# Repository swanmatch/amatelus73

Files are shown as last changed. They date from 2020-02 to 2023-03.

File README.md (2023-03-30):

# Amatelus73ビルドガイド

## 概要

m.teiさんの[セミエルゴレイアウト](https://github.com/mtei/SemiErgo_Layout)を参考に作成したシンメトリカルスタッガードキーボード。  
RGBMATRIXに標準対応しているのも特徴。

### 材料リスト

| 品目 | 数量 | 備考 |
| :--- | ---: | :--- |
| PCB |  1枚 |  |
| トッププレート |  1枚 |  |
| ボトムプレート |  1枚 |  |
| アクリル保護プレート |  2枚 |  |
| ProMicro |  1個 |  |
| ダイオード | 73個 | スピーカーを使う場合74個。<br>スルーホールは使えないので注意。 |
| LED(YS-SK6812mini) | 74個 |  |
| Kailhソケット | 73個 |  |
| M2L4ネジ | 18本 |  |
| M2L7六角スペーサ |  5本 |  |
| M2L8丸スペーサ |  4本 |  |
| タクトスイッチ |  1個 |  |
| ゴム足 |  4個 |  |
| 2Uスタビライザー |  4個 |  |
| MX互換スイッチ | 73個 |  |
| キーキャップ | 73個 |  |
| USBケーブル |  1本 |  |

### オプション機能

| 品目 | 数量 | 備考 |
| :--- | ---: | :--- |
| コンスルー |  2本 |  |
| 圧電サウンダ |  1個 | スピーカーオプション<br>型番: PKMCS1212E4000-R1 |
| 1kΩ抵抗 |  1個 | スピーカーオプション |
| OLED |  1個 | ピン、ソケットも。 |

## 組み立て手順

### LED

LEDをはんだ付けします。  
小さくドットが入っているのが欠けている足に対応しています。

行ごと向きが違うので注意してください。

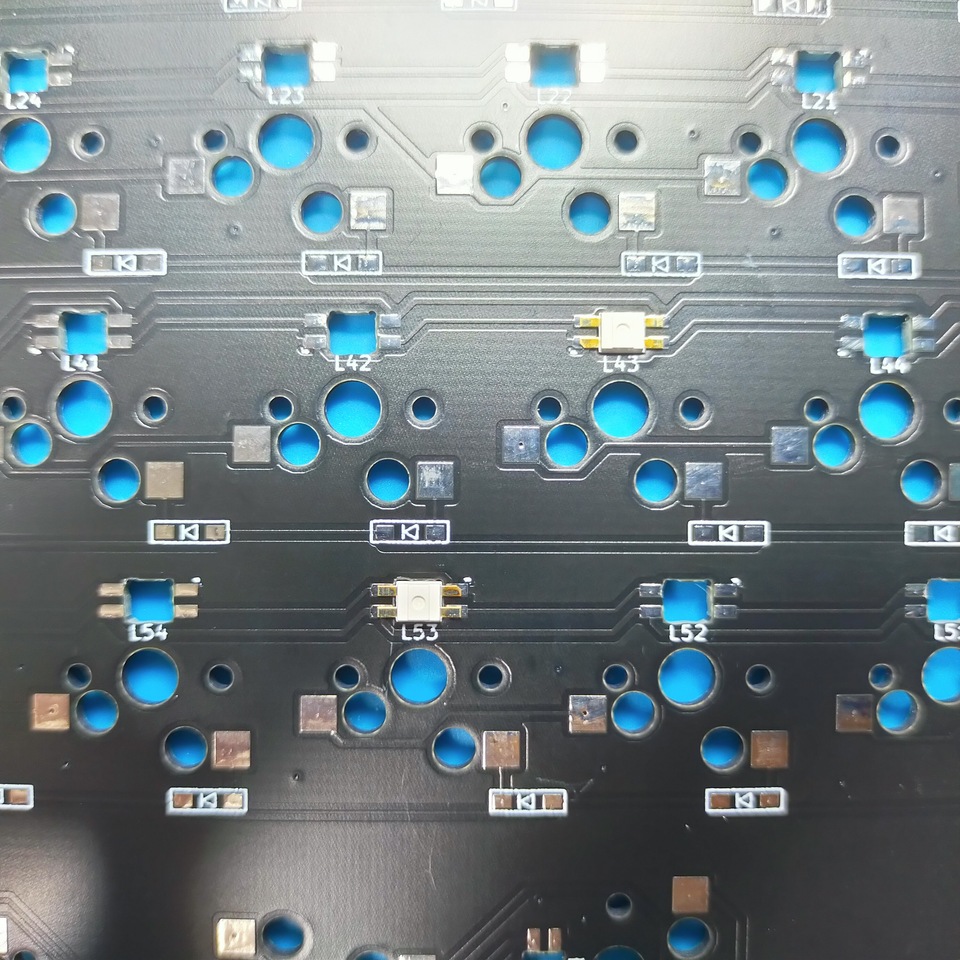
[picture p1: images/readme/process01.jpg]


### ダイオード

ダイオードをはんだ付けします。  
向きに気をつけてください。  
うっすら線が書いてあるほうが左です。

先に予備ハンダとしてどちらかのパッドにハンダを盛って、
予備ハンダを溶かすようにしてダイオードの片足をはんだ付けします。  
この状態で横から見てダイオードが浮いていないことを確認してください。  
浮いてしまっている場合はダイオードをピンセットで押さえつけながら、
はんだづけした部分を再度熱すればきれいになります。

浮いていないことを確認し、反対側をはんだ付けします。

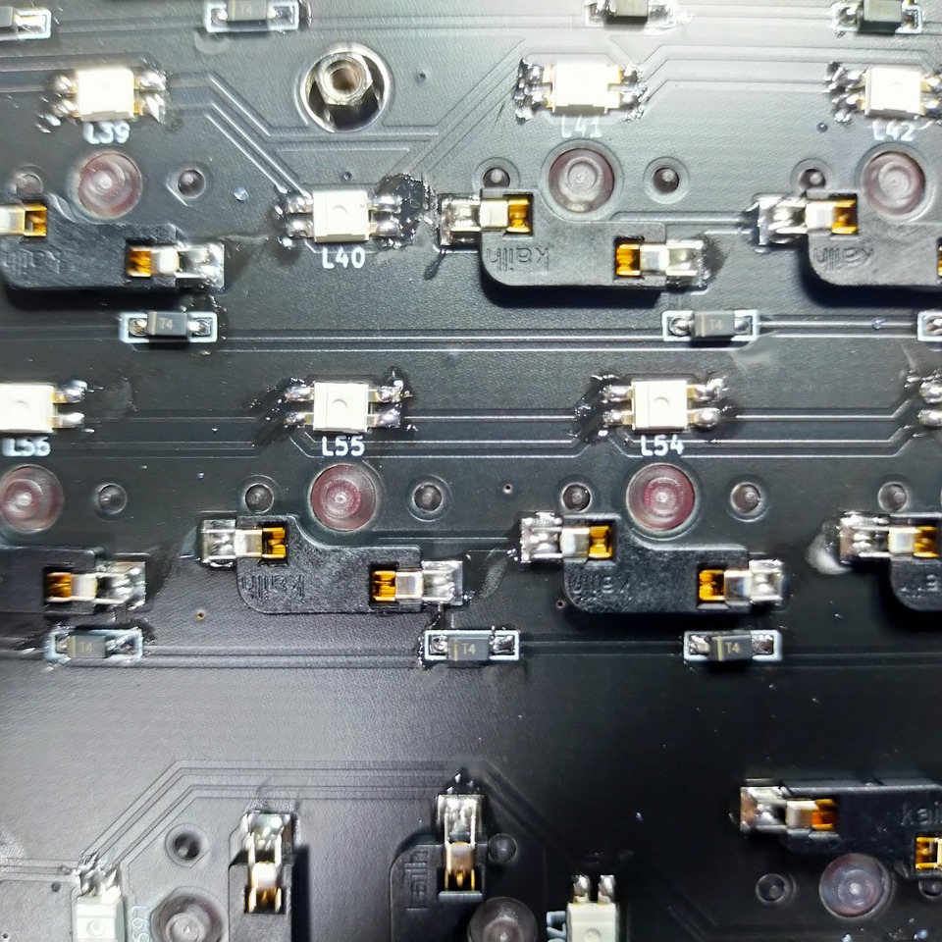
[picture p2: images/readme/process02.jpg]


### ソケット

ソケットをはんだ付けします。

### リセットスイッチ

反対側(表、スイッチ側)にひっくり返して、
タクトスイッチを差し込み、
再度裏面に戻してはんだ付けします。

### 圧電サウンダ(オプション)

1kΩ抵抗、ダイオード、圧電サウンダをはんだ付けします。

### ProMicro

ここだけは間違えるとリカバリが面倒なので、**細心の注意**をして作業にあたってください  
コンスルーを使う場合は[Helixのビルドガイド](https://github.com/MakotoKurauchi/helix/blob/master/Doc/buildguide_jp.md#pro-micro)などを参考にしてください。  
また、ProMicroはあらかじめいわゆる「モゲ対策」をしておくといいです。

まず4角のピンをはんだ付けし、
ピンヘッダとプロマイクロが浮いていないことを確認して、
他のピンをはんだ付けします。  
浮いてしまっていた場合、やけどに気を付けて、指で少し抑えながら、
浮いているピンにハンダをあてます。
裏面に戻し、表面と同様に4角からはんだ付けしていきます。

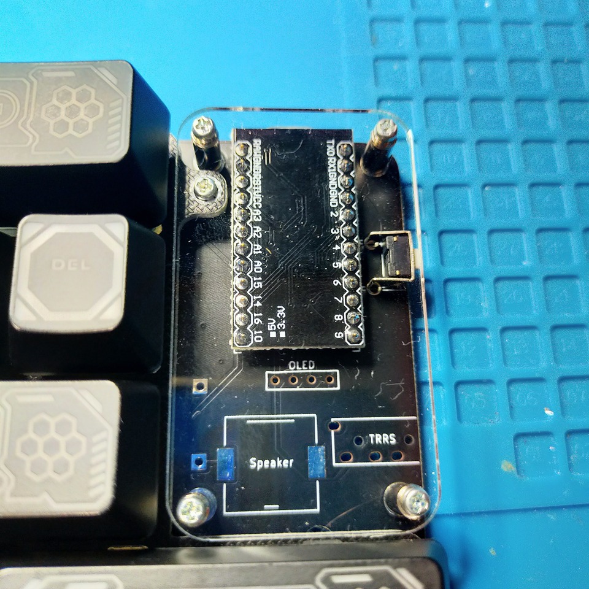
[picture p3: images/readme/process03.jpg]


この段階で一度後述のLEDテスト用のファームウェアの書き込みをして導通テストしておくといいです。  
問題なければ全LEDが点灯するはずです。  
(RGB_MATRIXはキー押下に応じてLEDが光るモードがデフォルトになっているようなのでLED_testで確認するのが吉です。)

```sh
git clone https://github.com/swanmatch/qmk_firmware.git --recursive
cd qmk_firmware
make amatelus73:led_test:avrdude
```

### OLED(オプション)

OLEDにピンをはんだ付けし、基板側にソケットをはんだ付けします。
いずれも斜めになりやすいので注意してください。

### スタビライザ

スタビライザを組み立てて、回路基板にはめ込みます。

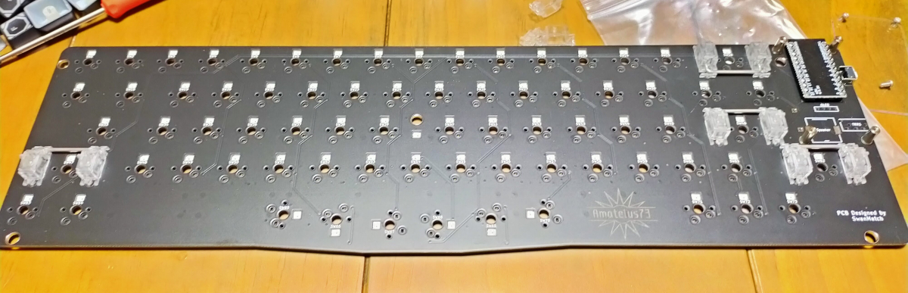
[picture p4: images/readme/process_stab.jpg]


### スイッチ、トッププレート

トッププレートにスイッチをはめて、PCBに刺します。  
これも最初に4角からはめるといいです。

### プロマイクロ保護プレート

PCB裏側から丸スペーサーをネジ止めして、
表側に保護プレートを挟み込む形でPCネジで止めます。

### ボトムプレート

ボトムプレートに六角スペーサーをネジ止めして、
本体にはめ込み、ネジ止めします。

ボトムプレートにゴム足を貼り付けてください。

### ファームウェア

ファームウェアの書き込みは以下のコマンドを叩きます。  
QMKの環境構築についてはお使いのOSによって異なりなりますので、
公式ドキュメントを読んでください。
```sh
# LEDテストの書き込みを実施した場合は↓は不要
git clone https://github.com/swanmatch/qmk_firmware.git --recursive
cd qmk_firmware
make amatelus73:default:avrdude
# OLED ver
# amatelus73/oled:default:avrdude
# Audio ver
# amatelus73/audio:default:avrdude
```

### キーキャップ

キーキャップの取り付けは下記を推奨しています。  
図はm.teiさんに作成いただきました。

Special Thanks!!

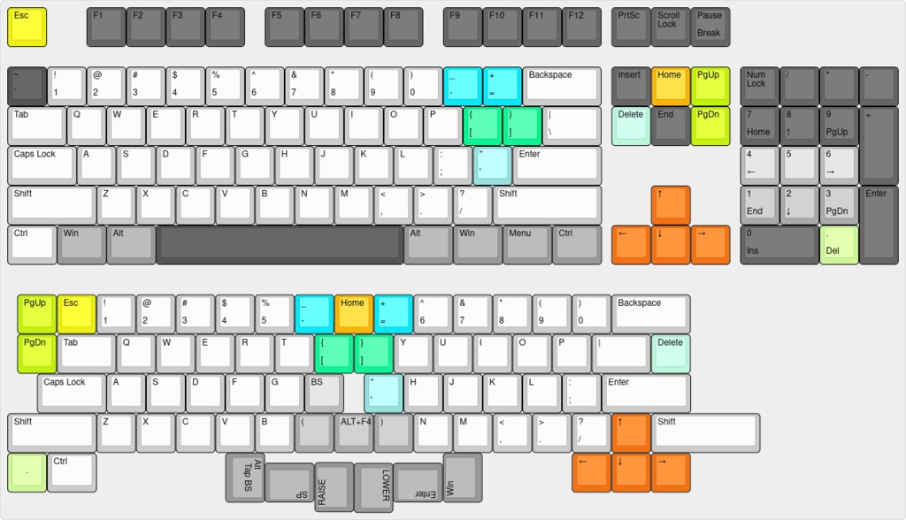
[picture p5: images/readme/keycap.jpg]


## 完成図

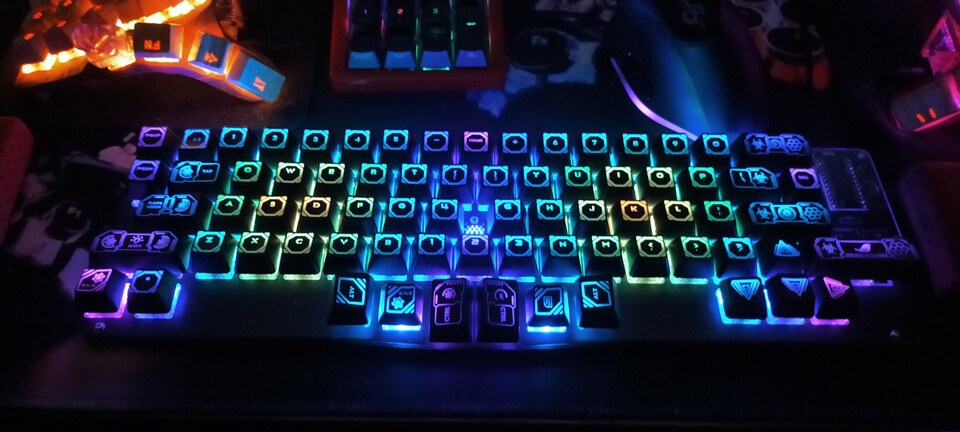
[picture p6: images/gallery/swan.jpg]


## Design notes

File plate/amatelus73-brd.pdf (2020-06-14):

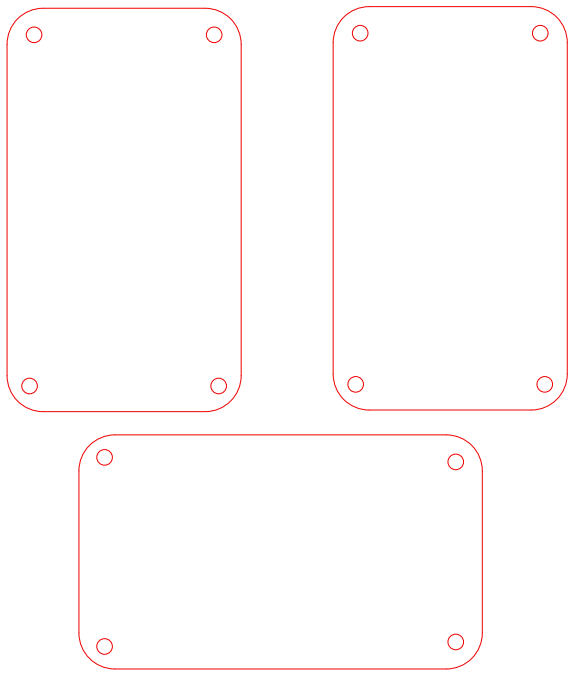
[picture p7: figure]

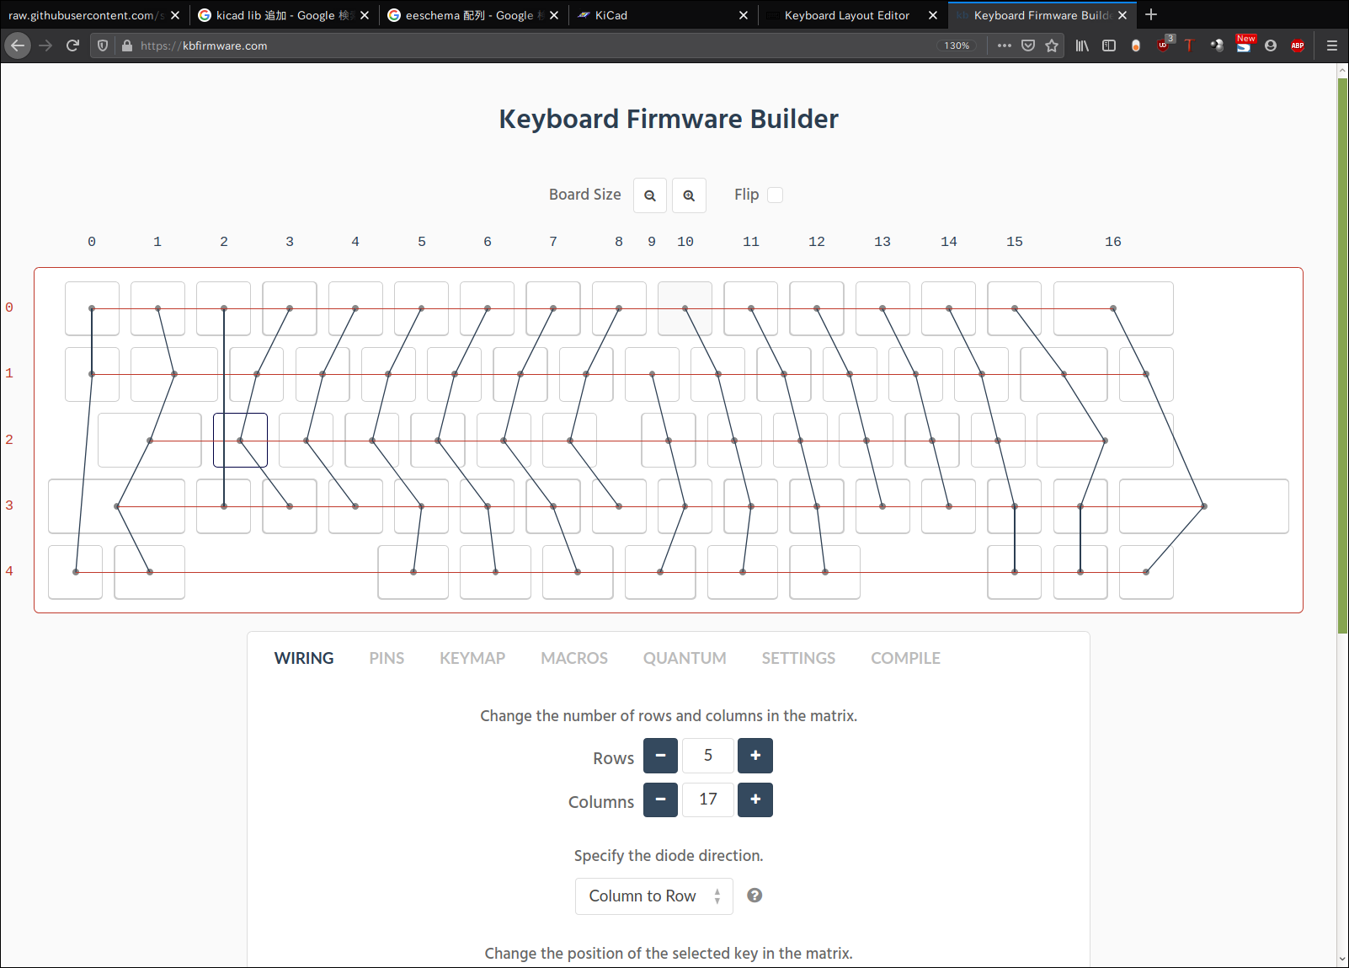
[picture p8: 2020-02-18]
haisen.png

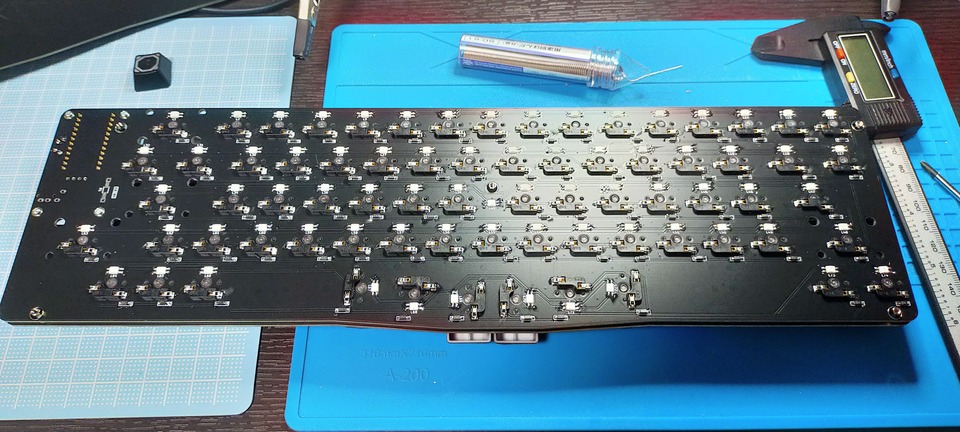
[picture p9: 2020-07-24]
images/readme/all.jpg

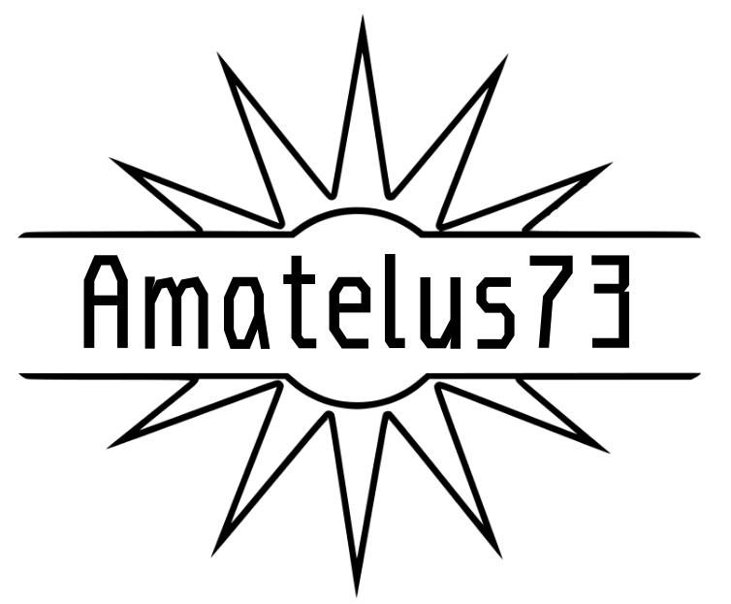
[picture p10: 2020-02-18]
bottom/amatelus73.png

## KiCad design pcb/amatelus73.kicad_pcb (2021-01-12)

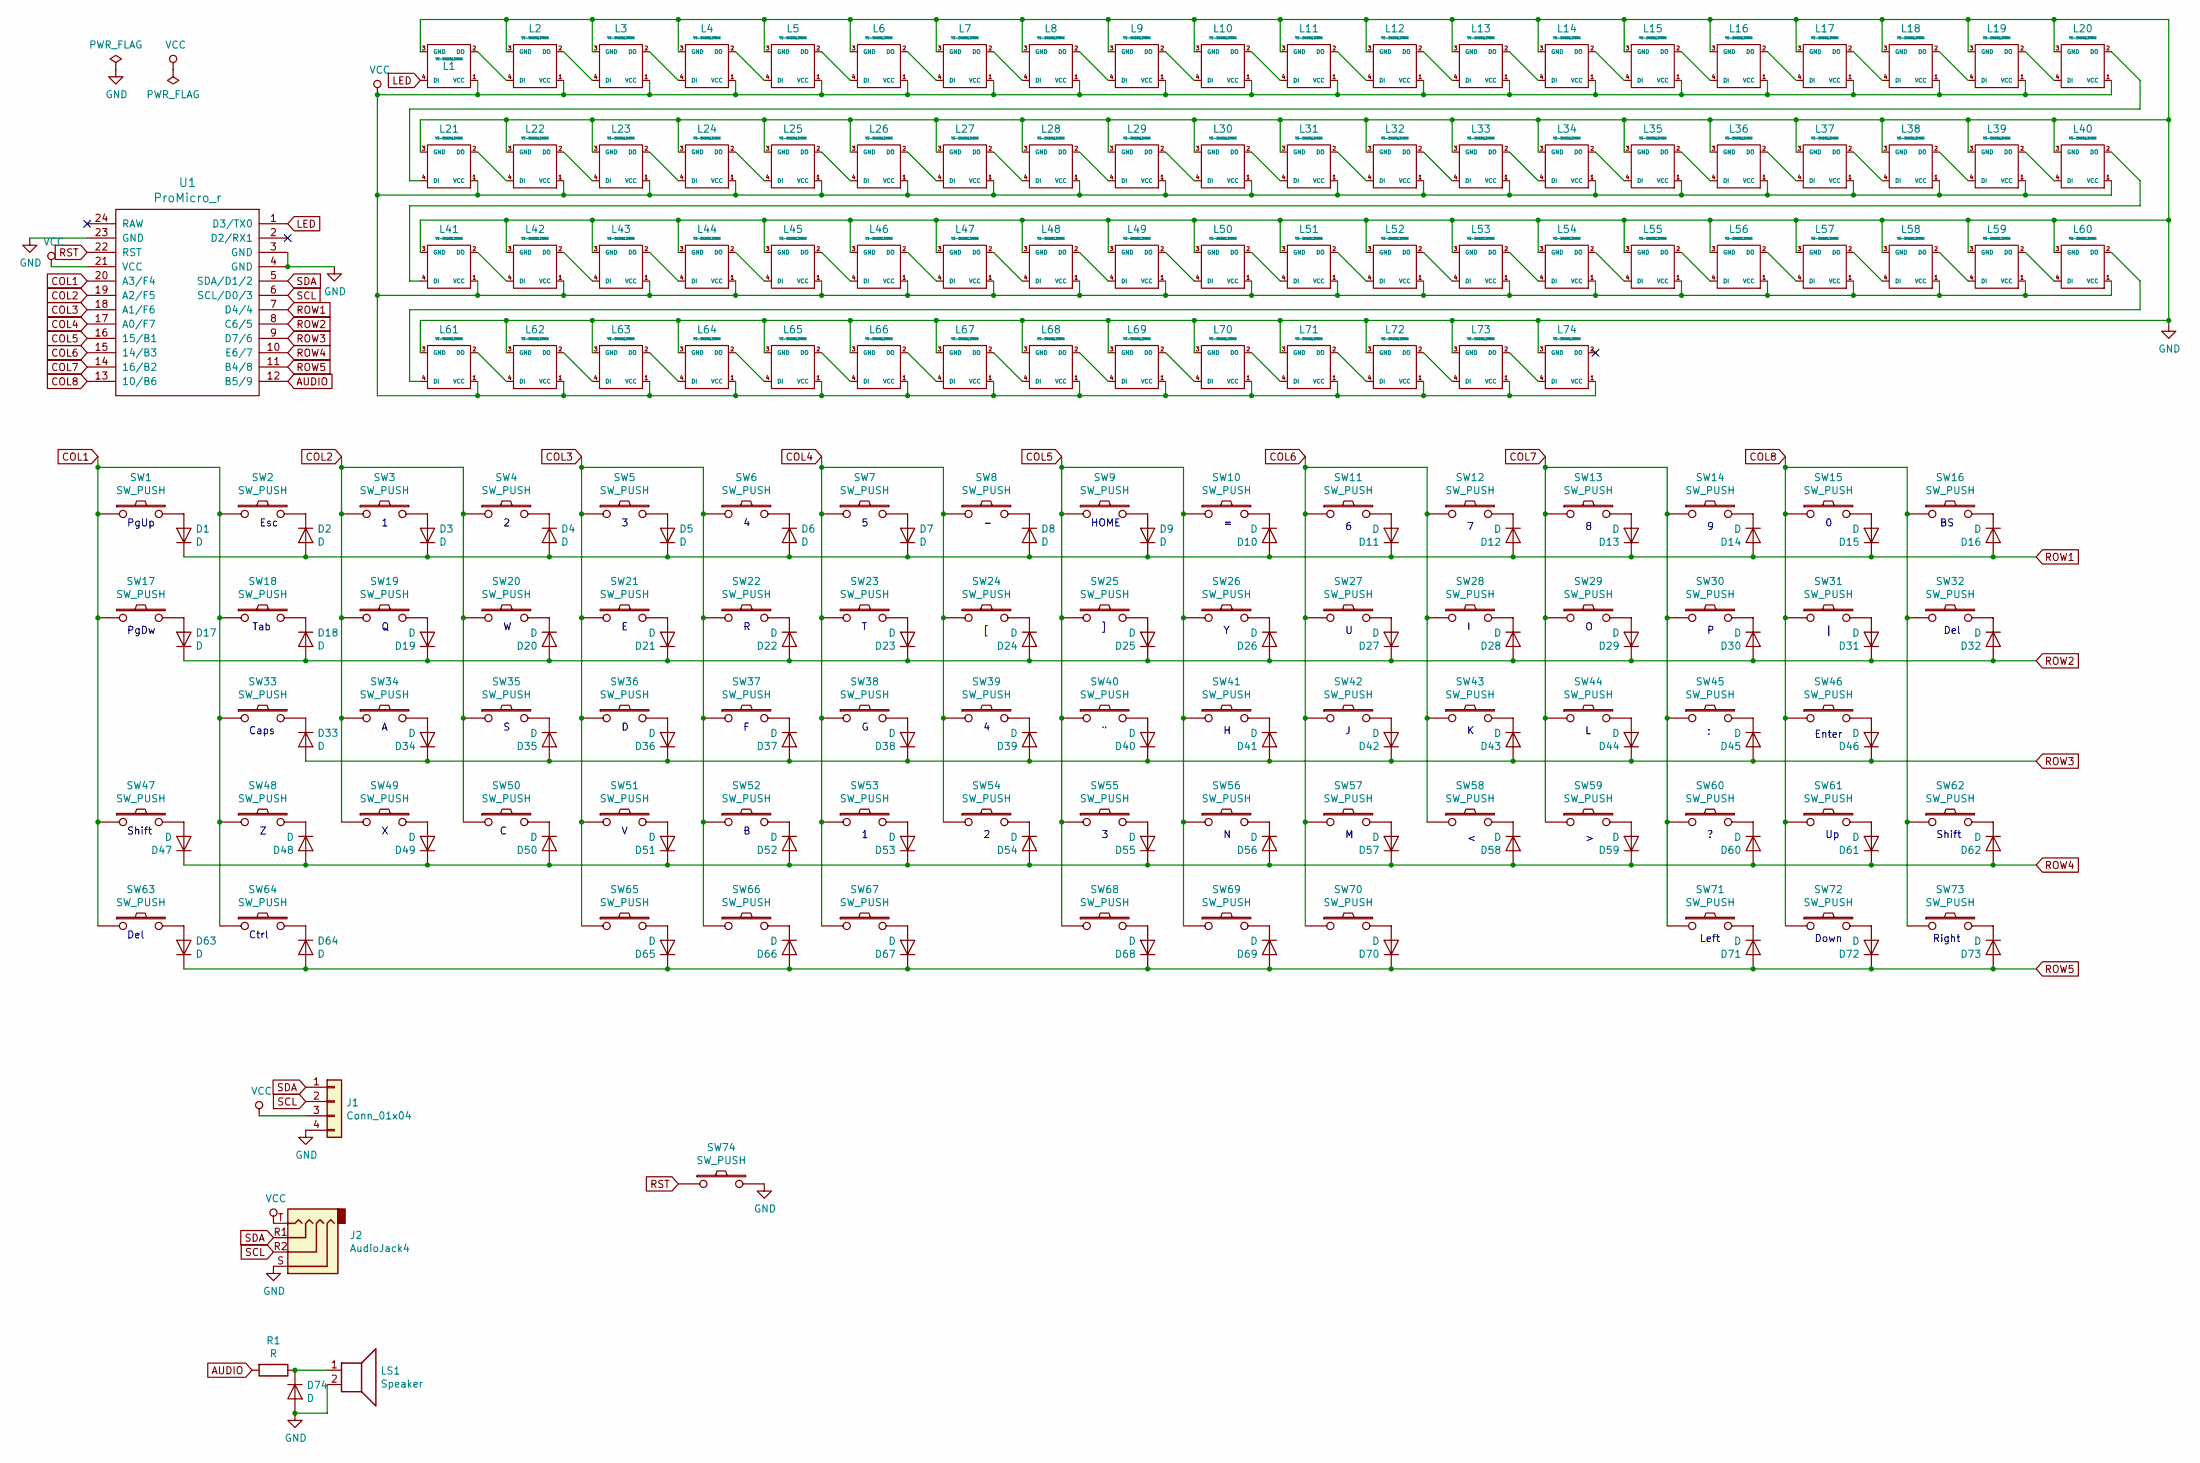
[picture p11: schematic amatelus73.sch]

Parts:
D1, D2, D3, D4, D5, D6, D7, D8, D9, D10, D11, D12, D13, D14, D15, D16, D17, D18, D19, D20, D21, D22, D23, D24, D25, D26, D27, D28, D29, D30, D31, D32, D33, D34, D35, D36, D37, D38, D39, D40, D41, D42, D43, D44, D45, D46, D47, D48, D49, D50, D51, D52, D53, D54, D55, D56, D57, D58, D59, D60, D61, D62, D63, D64, D65, D66, D67, D68, D69, D70, D71, D72, D73, D74: D; D3_SMD
J1: Conn_01x04; OLED_1side
J2: AudioJack4; MJ-4PP-9
L1, L2, L3, L4, L5, L6, L7, L8, L9, L10, L11, L12, L13, L14, L15, L16, L17, L18, L19, L20, L21, L22, L23, L24, L25, L26, L27, L28, L29, L30, L31, L32, L33, L34, L35, L36, L37, L38, L39, L40, L41, L42, L43, L44, L45, L46, L47, L48, L49, L50, L51, L52, L53, L54, L55, L56, L57, L58, L59, L60, L61, L62, L63, L64, L65, L66, L67, L68, L69, L70, L71, L72, L73, L74: YS-SK6812MINI; YS-SK6812MINI-E
LS1: Speaker; PKLCS1212E4001_HandSoldering
R1: R; Resistor_SMD+THTuniversal_1206_RM10_HandSoldering
SW1, SW2, SW3, SW4, SW5, SW6, SW7, SW8, SW9, SW10, SW11, SW12, SW13, SW14, SW15, SW16, SW17, SW19, SW20, SW21, SW22, SW23, SW24, SW25, SW26, SW27, SW28, SW29, SW30, SW32, SW34, SW35, SW36, SW37, SW38, SW39, SW40, SW41, SW42, SW43, SW44, SW45, SW48, SW49, SW50, SW51, SW52, SW53, SW54, SW55, SW56, SW57, SW58, SW59, SW60, SW61, SW63, SW71, SW72, SW73: SW_PUSH; CherryMX_Hotswap
SW18, SW31: SW_PUSH; CherryMX_Hotswap_1.5u
SW33: SW_PUSH; CherryMX_Hotswap_1.75u
SW46: SW_PUSH; CherryMX_Hotswap_2.25u
SW47, SW64, SW65, SW66, SW67, SW68, SW69, SW70: SW_PUSH; CherryMX_Hotswap_1.25u
SW62: SW_PUSH; CherryMX_Hotswap_2.75u
SW74: SW_PUSH; tact_switch2
U1: ProMicro_r; ProMicro_v3

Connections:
AUDIO: R1.2, U1.12 (B5/9)
COL1: SW1.1, SW2.1, SW17.1, SW18.1, SW33.1, SW47.1, SW48.1, SW63.1, SW64.1, U1.20 (A3/F4)
COL2: SW3.1, SW4.1, SW19.1, SW20.1, SW34.1, SW35.1, SW49.1, SW50.1, U1.19 (A2/F5)
COL3: SW5.1, SW6.1, SW21.1, SW22.1, SW36.1, SW37.1, SW51.1, SW52.1, SW65.1, SW66.1, U1.18 (A1/F6)
COL4: SW7.1, SW8.1, SW23.1, SW24.1, SW38.1, SW39.1, SW53.1, SW54.1, SW67.1, U1.17 (A0/F7)
COL5: SW9.1, SW10.1, SW25.1, SW26.1, SW40.1, SW41.1, SW55.1, SW56.1, SW68.1, SW69.1, U1.16 (15/B1)
COL6: SW11.1, SW12.1, SW27.1, SW28.1, SW42.1, SW43.1, SW57.1, SW58.1, SW70.1, U1.15 (14/B3)
COL7: SW13.1, SW14.1, SW29.1, SW30.1, SW44.1, SW45.1, SW59.1, SW60.1, SW71.1, U1.14 (16/B2)
COL8: SW15.1, SW16.1, SW31.1, SW32.1, SW46.1, SW61.1, SW62.1, SW72.1, SW73.1, U1.13 (10/B6)
GND: D74.2 (A), J1.4, J2.S, L1.3 (GND), L2.3 (GND), L3.3 (GND), L4.3 (GND), L5.3 (GND), L6.3 (GND), L7.3 (GND), L8.3 (GND), L9.3 (GND), L10.3 (GND), L11.3 (GND), L12.3 (GND), L13.3 (GND), L14.3 (GND), L15.3 (GND), L16.3 (GND), L17.3 (GND), L18.3 (GND), L19.3 (GND), L20.3 (GND), L21.3 (GND), L22.3 (GND), L23.3 (GND), L24.3 (GND), L25.3 (GND), L26.3 (GND), L27.3 (GND), L28.3 (GND), L29.3 (GND), L30.3 (GND), L31.3 (GND), L32.3 (GND), L33.3 (GND), L34.3 (GND), L35.3 (GND), L36.3 (GND), L37.3 (GND), L38.3 (GND), L39.3 (GND), L40.3 (GND), L41.3 (GND), L42.3 (GND), L43.3 (GND), L44.3 (GND), L45.3 (GND), L46.3 (GND), L47.3 (GND), L48.3 (GND), L49.3 (GND), L50.3 (GND), L51.3 (GND), L52.3 (GND), L53.3 (GND), L54.3 (GND), L55.3 (GND), L56.3 (GND), L57.3 (GND), L58.3 (GND), L59.3 (GND), L60.3 (GND), L61.3 (GND), L62.3 (GND), L63.3 (GND), L64.3 (GND), L65.3 (GND), L66.3 (GND), L67.3 (GND), L68.3 (GND), L69.3 (GND), L70.3 (GND), L71.3 (GND), L72.3 (GND), L73.3 (GND), L74.3 (GND), LS1.2, SW74.2, U1.3 (GND), U1.4 (GND), U1.23 (GND); also elsewhere on the board
LED: L1.4 (DI), U1.1 (D3/TX0)
unnamed: D1.2 (A), SW1.2
unnamed: D2.1 (K), SW2.2
unnamed: D3.2 (A), SW3.2
unnamed: D4.1 (K), SW4.2
unnamed: D5.2 (A), SW5.2
unnamed: D6.1 (K), SW6.2
unnamed: D7.2 (A), SW7.2
unnamed: D8.1 (K), SW8.2
unnamed: D9.2 (A), SW9.2
unnamed: D10.1 (K), SW10.2
unnamed: D11.2 (A), SW11.2
unnamed: D12.1 (K), SW12.2
unnamed: D13.2 (A), SW13.2
unnamed: D14.1 (K), SW14.2
unnamed: D15.2 (A), SW15.2
unnamed: D16.1 (K), SW16.2
unnamed: D17.2 (A), SW17.2
unnamed: D18.1 (K), SW18.2
unnamed: D19.2 (A), SW19.2
unnamed: D20.1 (K), SW20.2
unnamed: D21.2 (A), SW21.2
unnamed: D22.1 (K), SW22.2
unnamed: D23.2 (A), SW23.2
unnamed: D24.1 (K), SW24.2
unnamed: D25.2 (A), SW25.2
unnamed: D26.1 (K), SW26.2
unnamed: D27.2 (A), SW27.2
unnamed: D28.1 (K), SW28.2
unnamed: D29.2 (A), SW29.2
unnamed: D30.1 (K), SW30.2
unnamed: D31.2 (A), SW31.2
unnamed: D32.1 (K), SW32.2
unnamed: D33.1 (K), SW33.2
unnamed: D34.2 (A), SW34.2
unnamed: D35.1 (K), SW35.2
unnamed: D36.2 (A), SW36.2
unnamed: D37.1 (K), SW37.2
unnamed: D38.2 (A), SW38.2
unnamed: D39.1 (K), SW39.2
unnamed: D40.2 (A), SW40.2
unnamed: D41.1 (K), SW41.2
unnamed: D42.2 (A), SW42.2
unnamed: D43.1 (K), SW43.2
unnamed: D44.2 (A), SW44.2
unnamed: D45.1 (K), SW45.2
unnamed: D46.2 (A), SW46.2
unnamed: D47.2 (A), SW47.2
unnamed: D48.1 (K), SW48.2
unnamed: D49.2 (A), SW49.2
unnamed: D50.1 (K), SW50.2
unnamed: D51.2 (A), SW51.2
unnamed: D52.1 (K), SW52.2
unnamed: D53.2 (A), SW53.2
unnamed: D54.1 (K), SW54.2
unnamed: D55.2 (A), SW55.2
unnamed: D56.1 (K), SW56.2
unnamed: D57.2 (A), SW57.2
unnamed: D58.1 (K), SW58.2
unnamed: D59.2 (A), SW59.2
unnamed: D60.1 (K), SW60.2
unnamed: D61.2 (A), SW61.2
unnamed: D62.1 (K), SW62.2
unnamed: D63.2 (A), SW63.2
unnamed: D64.1 (K), SW64.2
unnamed: D65.2 (A), SW65.2
unnamed: D66.1 (K), SW66.2
unnamed: D67.2 (A), SW67.2
unnamed: D68.2 (A), SW68.2
unnamed: D69.1 (K), SW69.2
unnamed: D70.2 (A), SW70.2
unnamed: D71.1 (K), SW71.2
unnamed: D72.2 (A), SW72.2
unnamed: D73.1 (K), SW73.2
unnamed 84: D74.1 (K), LS1.1, R1.1; also elsewhere on the board
unnamed: L1.2 (DO), L2.4 (DI)
unnamed: L2.2 (DO), L3.4 (DI)
unnamed: L3.2 (DO), L4.4 (DI)
unnamed: L4.2 (DO), L5.4 (DI)
unnamed: L5.2 (DO), L6.4 (DI)
unnamed: L6.2 (DO), L7.4 (DI)
unnamed: L7.2 (DO), L8.4 (DI)
unnamed: L8.2 (DO), L9.4 (DI)
unnamed: L10.2 (DO), L11.4 (DI)
unnamed: L9.2 (DO), L10.4 (DI)
unnamed: L11.2 (DO), L12.4 (DI)
unnamed: L12.2 (DO), L13.4 (DI)
unnamed: L13.2 (DO), L14.4 (DI)
unnamed: L14.2 (DO), L15.4 (DI)
unnamed: L15.2 (DO), L16.4 (DI)
unnamed: L16.2 (DO), L17.4 (DI)
unnamed: L17.2 (DO), L18.4 (DI)
unnamed: L18.2 (DO), L19.4 (DI)
unnamed: L19.2 (DO), L20.4 (DI)
unnamed: L20.2 (DO), L21.4 (DI)
unnamed: L21.2 (DO), L22.4 (DI)
unnamed: L22.2 (DO), L23.4 (DI)
unnamed: L23.2 (DO), L24.4 (DI)
unnamed: L24.2 (DO), L25.4 (DI)
unnamed: L25.2 (DO), L26.4 (DI)
unnamed: L26.2 (DO), L27.4 (DI)
unnamed: L27.2 (DO), L28.4 (DI)
unnamed: L28.2 (DO), L29.4 (DI)
unnamed: L29.2 (DO), L30.4 (DI)
unnamed: L30.2 (DO), L31.4 (DI)
unnamed: L31.2 (DO), L32.4 (DI)
unnamed: L32.2 (DO), L33.4 (DI)
unnamed: L33.2 (DO), L34.4 (DI)
unnamed: L34.2 (DO), L35.4 (DI)
unnamed: L35.2 (DO), L36.4 (DI)
unnamed: L36.2 (DO), L37.4 (DI)
unnamed: L37.2 (DO), L38.4 (DI)
unnamed: L38.2 (DO), L39.4 (DI)
unnamed: L39.2 (DO), L40.4 (DI)
unnamed: L40.2 (DO), L41.4 (DI)
unnamed: L41.2 (DO), L42.4 (DI)
unnamed: L42.2 (DO), L43.4 (DI)
unnamed: L43.2 (DO), L44.4 (DI)
unnamed: L44.2 (DO), L45.4 (DI)
unnamed: L45.2 (DO), L46.4 (DI)
unnamed: L46.2 (DO), L47.4 (DI)
unnamed: L47.2 (DO), L48.4 (DI)
unnamed: L48.2 (DO), L49.4 (DI)
unnamed: L49.2 (DO), L50.4 (DI)
unnamed: L50.2 (DO), L51.4 (DI)
unnamed: L51.2 (DO), L52.4 (DI)
unnamed: L52.2 (DO), L53.4 (DI)
unnamed: L53.2 (DO), L54.4 (DI)
unnamed: L54.2 (DO), L55.4 (DI)
unnamed: L55.2 (DO), L56.4 (DI)
unnamed: L56.2 (DO), L57.4 (DI)
unnamed: L57.2 (DO), L58.4 (DI)
unnamed: L58.2 (DO), L59.4 (DI)
unnamed: L59.2 (DO), L60.4 (DI)
unnamed: L60.2 (DO), L61.4 (DI)
unnamed: L61.2 (DO), L62.4 (DI)
unnamed: L62.2 (DO), L63.4 (DI)
unnamed: L63.2 (DO), L64.4 (DI)
unnamed: L64.2 (DO), L65.4 (DI)
unnamed: L65.2 (DO), L66.4 (DI)
unnamed: L66.2 (DO), L67.4 (DI)
unnamed: L67.2 (DO), L68.4 (DI)
unnamed: L68.2 (DO), L69.4 (DI)
unnamed: L69.2 (DO), L70.4 (DI)
unnamed: L70.2 (DO), L71.4 (DI)
unnamed: L71.2 (DO), L72.4 (DI)
unnamed: L72.2 (DO), L73.4 (DI)
unnamed: L73.2 (DO), L74.4 (DI)
ROW1: D1.1 (K), D2.2 (A), D3.1 (K), D4.2 (A), D5.1 (K), D6.2 (A), D7.1 (K), D8.2 (A), D9.1 (K), D10.2 (A), D11.1 (K), D12.2 (A), D13.1 (K), D14.2 (A), D15.1 (K), D16.2 (A), U1.7 (D4/4)
ROW2: D17.1 (K), D18.2 (A), D19.1 (K), D20.2 (A), D21.1 (K), D22.2 (A), D23.1 (K), D24.2 (A), D25.1 (K), D26.2 (A), D27.1 (K), D28.2 (A), D29.1 (K), D30.2 (A), D31.1 (K), D32.2 (A), U1.8 (C6/5)
ROW3: D33.2 (A), D34.1 (K), D35.2 (A), D36.1 (K), D37.2 (A), D38.1 (K), D39.2 (A), D40.1 (K), D41.2 (A), D42.1 (K), D43.2 (A), D44.1 (K), D45.2 (A), D46.1 (K), U1.9 (D7/6)
ROW4: D47.1 (K), D48.2 (A), D49.1 (K), D50.2 (A), D51.1 (K), D52.2 (A), D53.1 (K), D54.2 (A), D55.1 (K), D56.2 (A), D57.1 (K), D58.2 (A), D59.1 (K), D60.2 (A), D61.1 (K), D62.2 (A), U1.10 (E6/7)
ROW5: D63.1 (K), D64.2 (A), D65.1 (K), D66.2 (A), D67.1 (K), D68.1 (K), D69.2 (A), D70.1 (K), D71.2 (A), D72.1 (K), D73.2 (A), U1.11 (B4/8)
RST: SW74.1, U1.22 (RST)
SCL: J1.2, J2.R2, U1.6 (SCL/D0/3); also elsewhere on the board
SDA: J1.1, J2.R1, U1.5 (SDA/D1/2); also elsewhere on the board
VCC: J1.3, J2.T, L1.1 (VCC), L2.1 (VCC), L3.1 (VCC), L4.1 (VCC), L5.1 (VCC), L6.1 (VCC), L7.1 (VCC), L8.1 (VCC), L9.1 (VCC), L10.1 (VCC), L11.1 (VCC), L12.1 (VCC), L13.1 (VCC), L14.1 (VCC), L15.1 (VCC), L16.1 (VCC), L17.1 (VCC), L18.1 (VCC), L19.1 (VCC), L20.1 (VCC), L21.1 (VCC), L22.1 (VCC), L23.1 (VCC), L24.1 (VCC), L25.1 (VCC), L26.1 (VCC), L27.1 (VCC), L28.1 (VCC), L29.1 (VCC), L30.1 (VCC), L31.1 (VCC), L32.1 (VCC), L33.1 (VCC), L34.1 (VCC), L35.1 (VCC), L36.1 (VCC), L37.1 (VCC), L38.1 (VCC), L39.1 (VCC), L40.1 (VCC), L41.1 (VCC), L42.1 (VCC), L43.1 (VCC), L44.1 (VCC), L45.1 (VCC), L46.1 (VCC), L47.1 (VCC), L48.1 (VCC), L49.1 (VCC), L50.1 (VCC), L51.1 (VCC), L52.1 (VCC), L53.1 (VCC), L54.1 (VCC), L55.1 (VCC), L56.1 (VCC), L57.1 (VCC), L58.1 (VCC), L59.1 (VCC), L60.1 (VCC), L61.1 (VCC), L62.1 (VCC), L63.1 (VCC), L64.1 (VCC), L65.1 (VCC), L66.1 (VCC), L67.1 (VCC), L68.1 (VCC), L69.1 (VCC), L70.1 (VCC), L71.1 (VCC), L72.1 (VCC), L73.1 (VCC), L74.1 (VCC), U1.21 (VCC); also elsewhere on the board

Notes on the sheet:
PgUp
Esc
HOME
PgDw
Tab
Caps
Shift
Ctrl
Del
Left
Down
Right
Enter

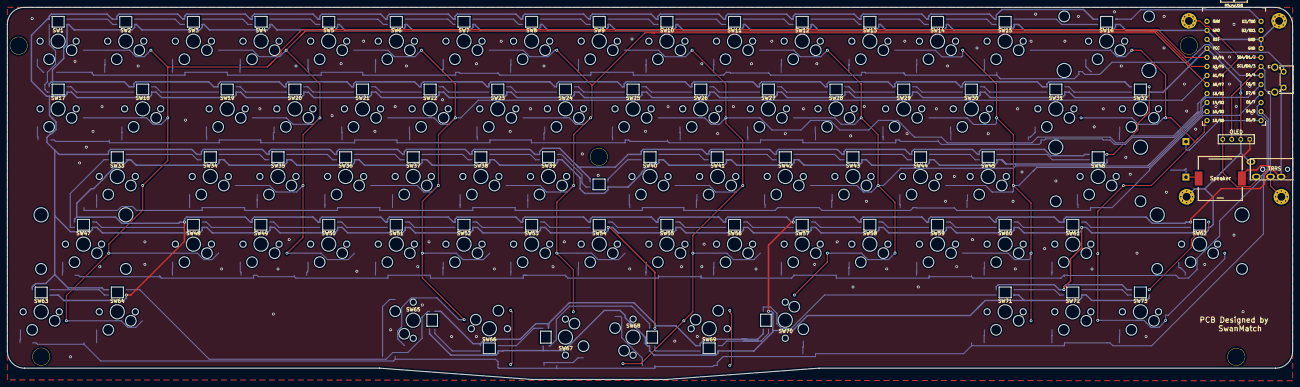
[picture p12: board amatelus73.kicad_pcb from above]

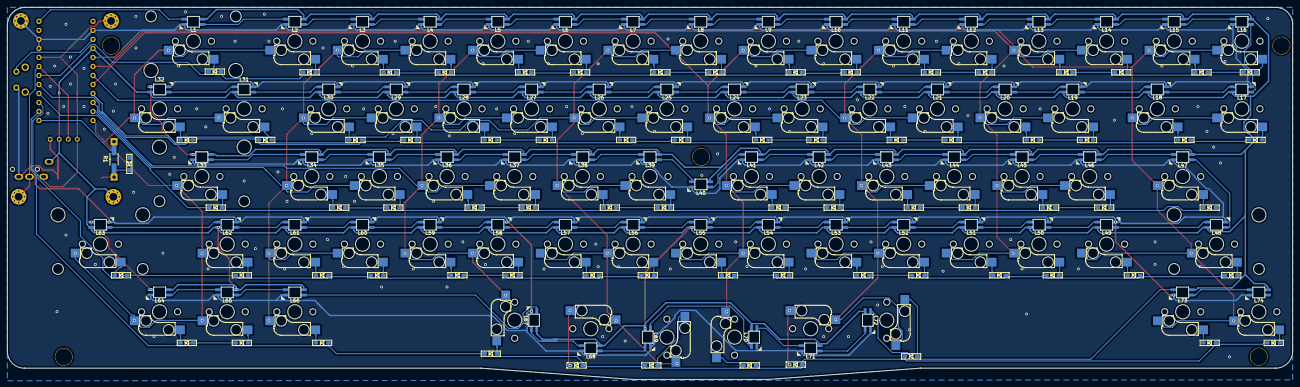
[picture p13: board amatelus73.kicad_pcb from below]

Board: 2 copper layers, 361.9 x 104.8 mm, 236 parts (149 on the bottom side), 167 nets.

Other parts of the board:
Hole1, Hole2, Hole3, Hole4, Hole5: Val**; HOLE
SC1, SC2, SC3, SC4: MountingHole_2.2mm_M2_Pad_Via
Speaker: Speaker; PKLCS1212E4001_HandSoldering

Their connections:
GND: SC2.1, Speaker.2; also elsewhere on the board
unnamed 84: Speaker.1; also elsewhere on the board
SCL: SC4.1; also elsewhere on the board
SDA: SC1.1; also elsewhere on the board
VCC: SC3.1; also elsewhere on the board

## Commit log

2020-02-18 first order
    [amatelus73-B.Cu.gbl, amatelus73-B.Mask.gbs, amatelus73-B.Paste.gbp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]
2020-06-14 2nd order
    [amatelus73-B.Cu.gbl, amatelus73-B.Mask.gbs, amatelus73-B.Paste.gbp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]
2021-01-12 fix silk
    [amatelus73-B_Cu.gbl, amatelus73-B_Mask.gbs, amatelus73-B_Paste.gbp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]
